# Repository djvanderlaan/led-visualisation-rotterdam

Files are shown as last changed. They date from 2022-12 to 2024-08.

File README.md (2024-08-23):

# LED Visualisation of Rotterdam

The visualisation consists of a number of 3D-printed 'light boxes' for each of the districts in the municipality of Rotterdam in The Netherlands. By inserting punch cards into the model, users are able to select different datasets for the visualisation. This was built as a prototype. The goal is invite users to look and play with statistical data.

Using a map of all districts in The Netherlands ([CBS and Kadaster](https://www.cbs.nl/nl-nl/dossier/nederland-regionaal/geografische-data/wijk-en-buurtkaart-2020)), the districts of Rotterdam were selected and each district was scaled and written to SVG-file. These were converted to 3D-models using OpenSCAD. The boxes were printed in white PLA and the covers were printed in transparent PLA. Holes were drilled in the back for the LEDS (took some experimenting to find the correct number and positions). The boxes were attached to each other using a 3D-printing pen and were attached to a muliplex board. 

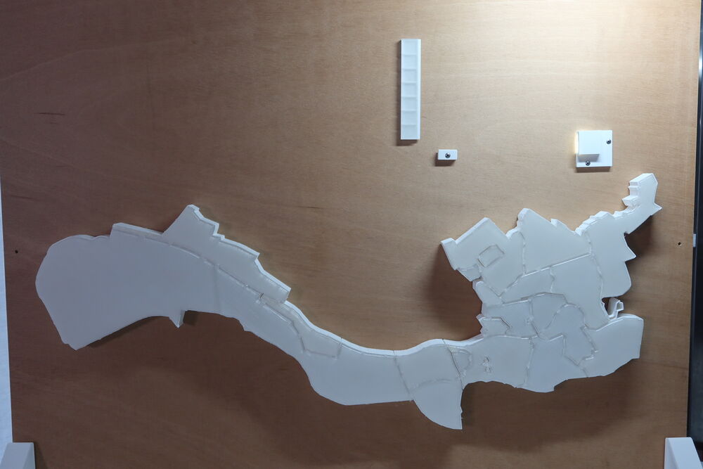
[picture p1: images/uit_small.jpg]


Getting the correct diffusion of the LEDs took some experimenting. In the end small domes were printed in vase mode and glued over the LEDs. Furthermore a layer of LED foam was taped to the inside of the covers. However, even then the lighting in some of the larger districted is still not completely uniform. More LEDs would help; also the diffusors can probably be impoved upon. 

### Card 0: percentage of households with an income below or around the social minimum

[Data is from StatLine](https://opendata.cbs.nl/statline/#/CBS/nl/dataset/84799NED/table?dl=77FE6)

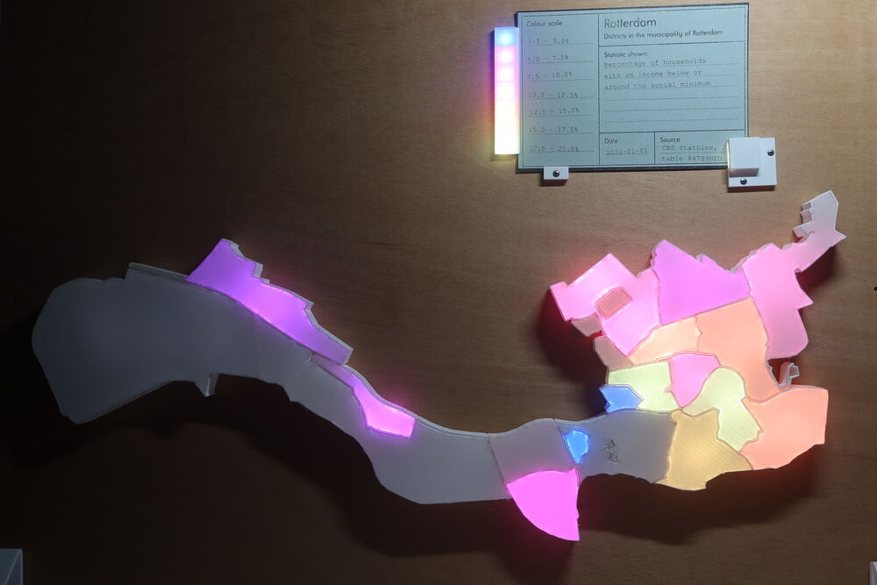
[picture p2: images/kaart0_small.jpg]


### Card 1: number of business locations per square kilometre

[Data is from StatLine](https://opendata.cbs.nl/statline/#/CBS/nl/dataset/84799NED/table?dl=77FE7)

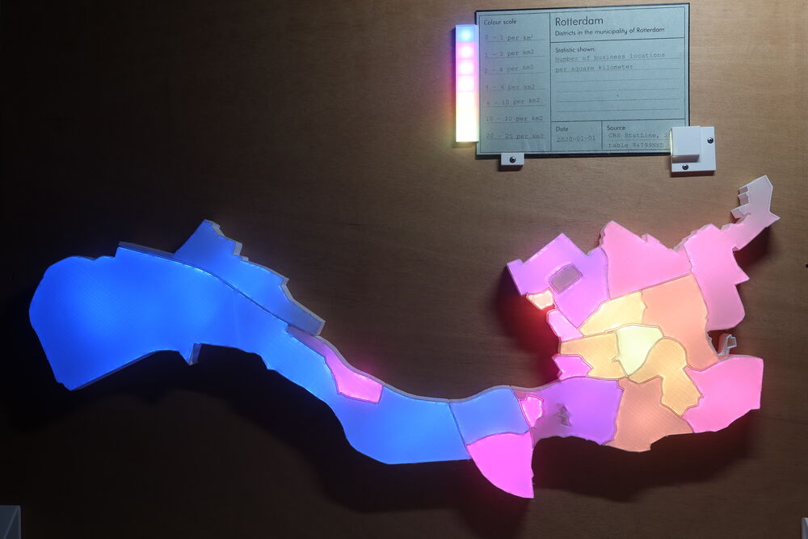
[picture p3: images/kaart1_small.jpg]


### Card 2: Degree of urbanisation as measured by the local address density

[Data is from StatLine](https://opendata.cbs.nl/statline/#/CBS/nl/dataset/84799NED/table?dl=77FE4)

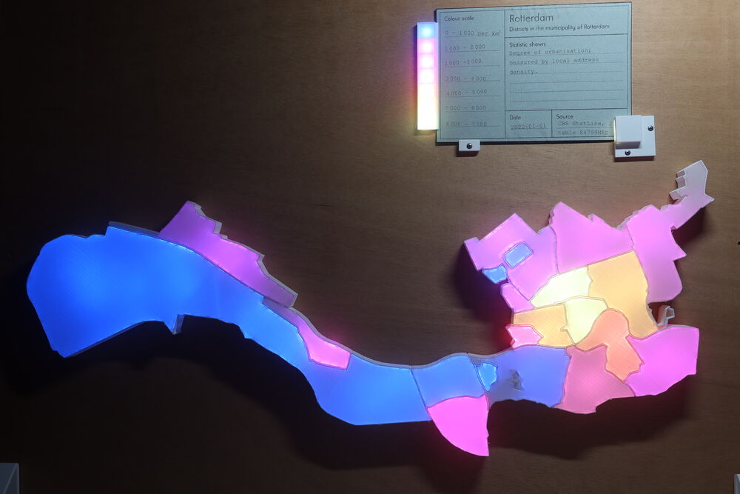
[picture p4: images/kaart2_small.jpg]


### Card 3: Average social economic status based on welfare, education and recent labour force participation

[Data is from StatLine](https://opendata.cbs.nl/statline/#/CBS/nl/dataset/85163NED/table?dl=77FD9)

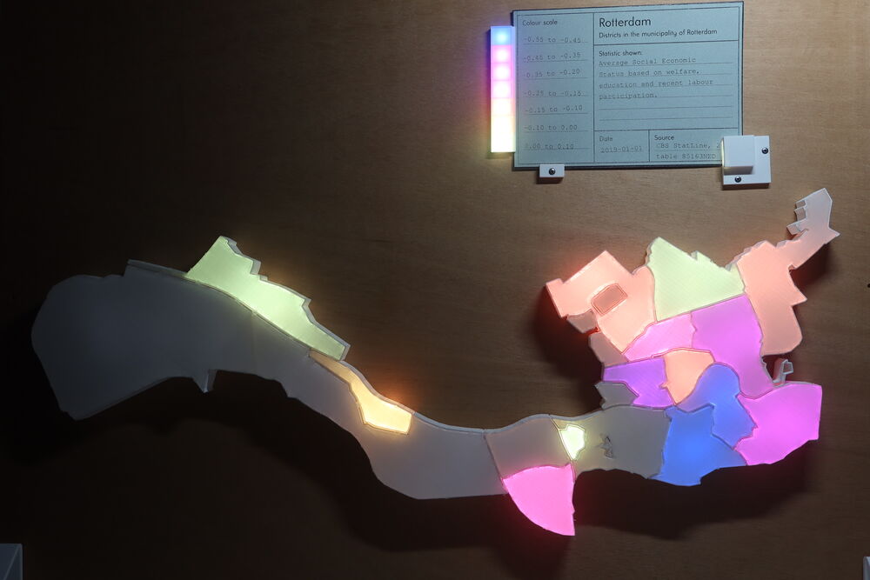
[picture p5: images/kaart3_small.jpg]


### Card 4: Diversity in social economic status

[Data is from StatLine](https://opendata.cbs.nl/statline/#/CBS/nl/dataset/85163NED/table?dl=77FD9)

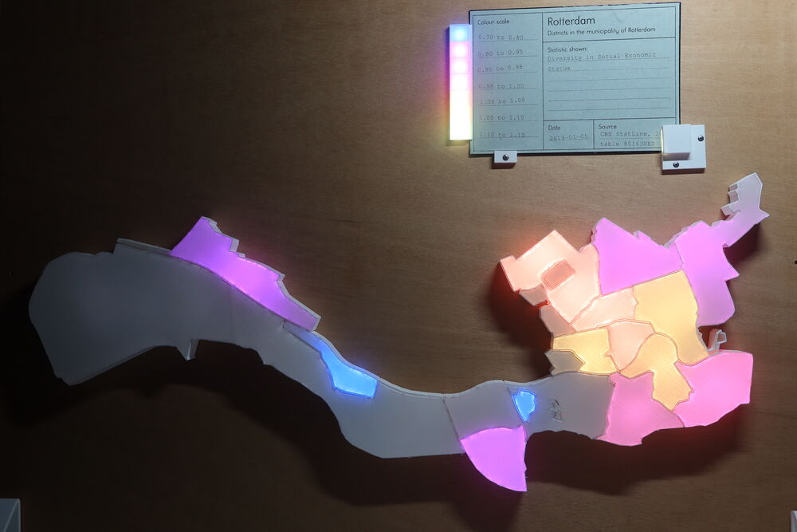
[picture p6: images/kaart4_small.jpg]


### Card 5: Change in the average social economic status from 2014 to 2019

[Data is from StatLine](https://opendata.cbs.nl/statline/#/CBS/nl/dataset/85163NED/table?dl=77FD9)

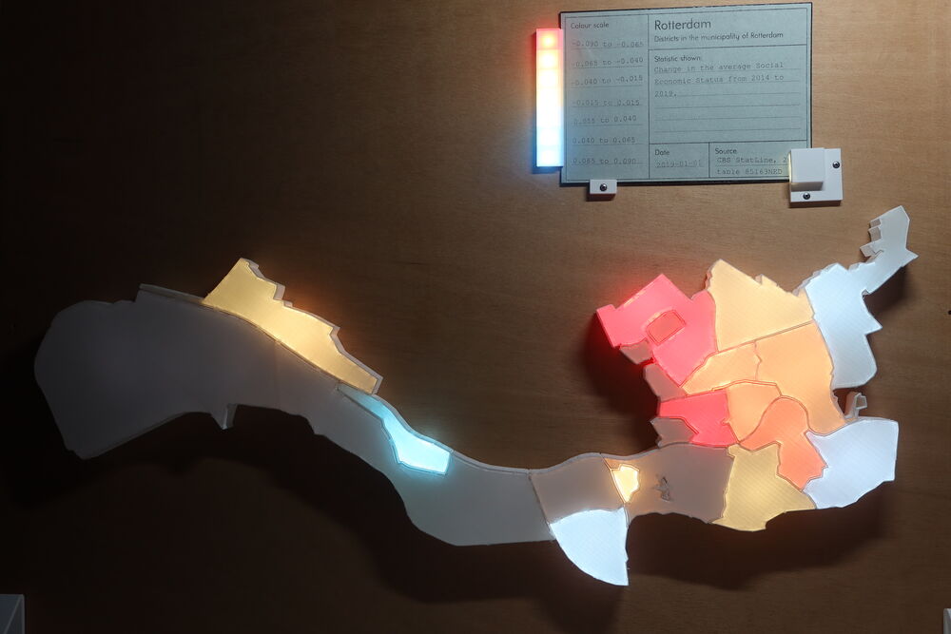
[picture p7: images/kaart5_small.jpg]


### Card 6: Percentage of persons aged younger than 25 years old

[Data is from StatLine](https://opendata.cbs.nl/statline/#/CBS/nl/dataset/84799NED/table?dl=77FE8)

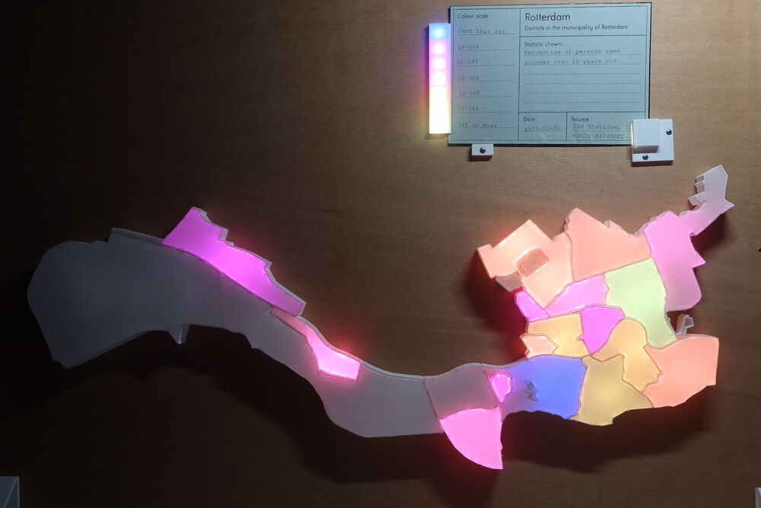
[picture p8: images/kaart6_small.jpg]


### Back side

The visualisation is controlled by an Arduino Uno. All data is in the RAM of Uno. Three LEDs in combination with three photoresistors are responsible for reading out the cards. The cards canhave up to three holes in them. This means that there are 7 possible cards (numbers 0 to 6). All lights active (three holes; or no card) switches of the visualisation. The visualisation itself uses AP102 controllable RGB LEDs. The final 7 LEDS are the colour scale. Colour scales are also stored on the Uno. These consist of 7 colours + a no data colour. Each of the colours comes in two brighnesses. So in total there are 16 colours in one colour scale. The less bright colours are used for the smaller districts. This is to correct for the smaller area of the districts; this makes the light from the LEDs seem brighter. 

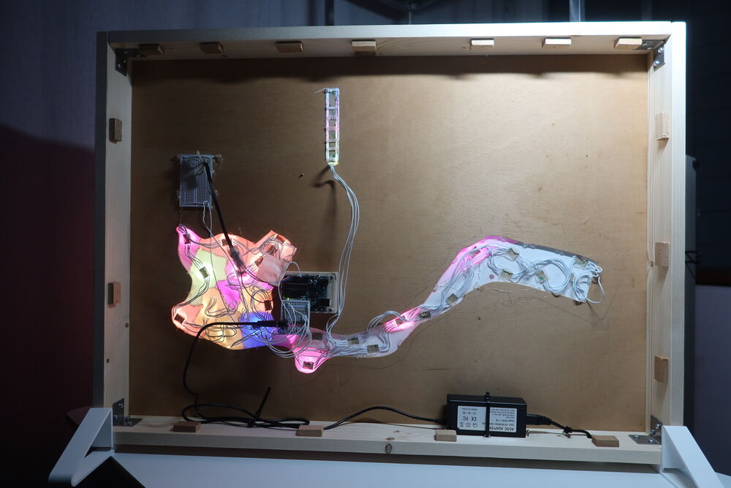
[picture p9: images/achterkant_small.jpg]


## Software

Code was written in the Arduino IDE. Models were made with R, OpenSCAD and FreeCAD. Data for uploading to the Arduino was prepared using R.

## Also see

[ntteloos.nl/rotterdam](https://ntteloos.nl/rotterdam)

[3D-models kan be found on Printables](https://www.printables.com/model/397711-led-visualisation-of-rotterdam).

## Licence

The code and models in this repository are licensed under [CC BY-SA 4.0](https://creativecommons.org/licenses/by-sa/4.0/).

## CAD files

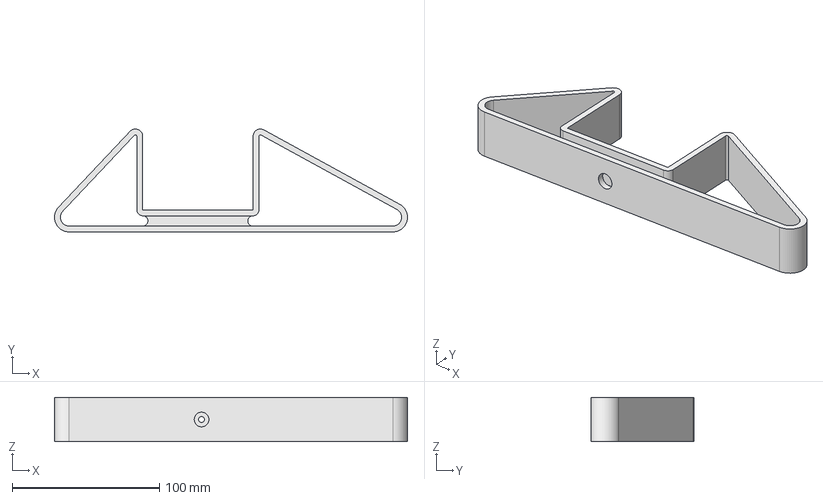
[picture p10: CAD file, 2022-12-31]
models/base/base.FCStd
240.0 x 70.0 x 30.0 mm

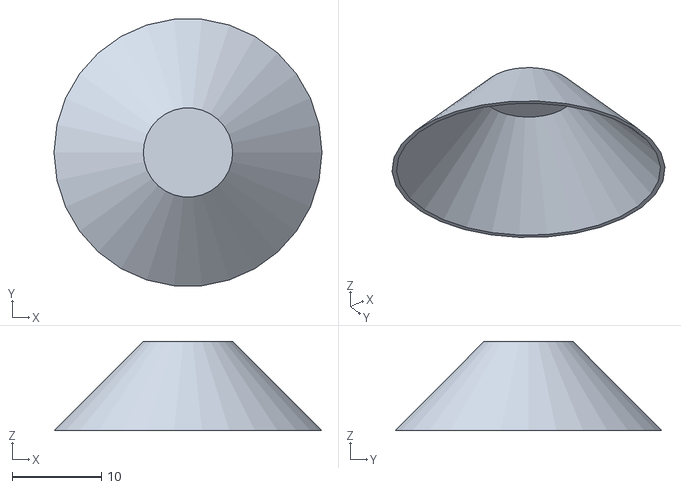
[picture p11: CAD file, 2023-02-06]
models/diffuser/diffuser_v0_30_10.stl
30.0 x 29.8 x 10.0

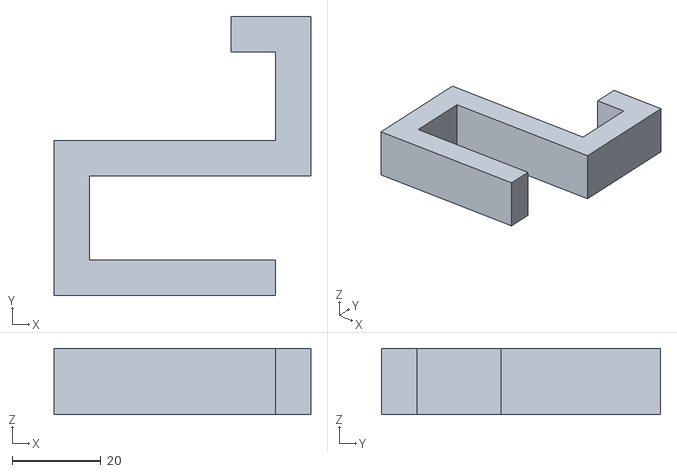
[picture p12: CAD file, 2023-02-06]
models/fixtures/hook.stl
58.0 x 63.0 x 15.0

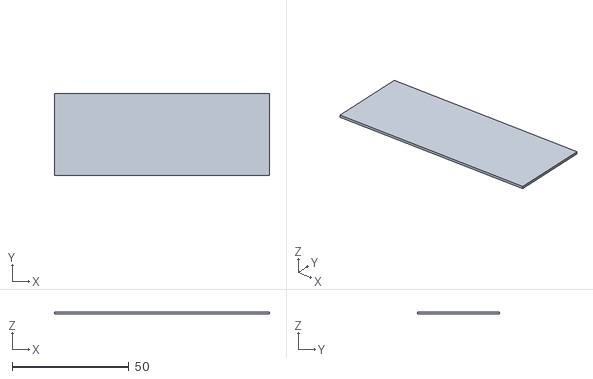
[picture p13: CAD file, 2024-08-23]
punch_card_reader/card_text/signature.stl
92.0 x 35.0 x 1.00

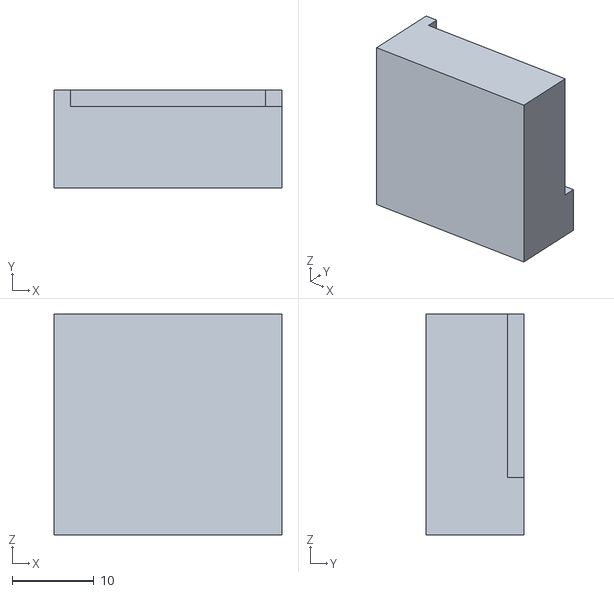
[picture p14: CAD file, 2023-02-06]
punch_card_reader/reader_cover.stl
27.9 x 12.0 x 27.0

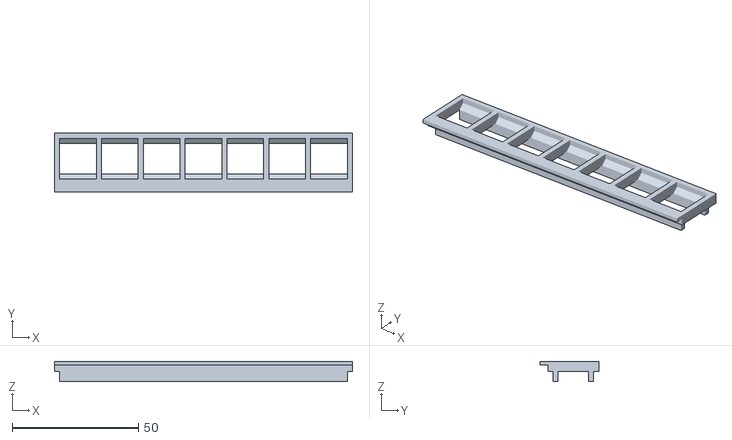
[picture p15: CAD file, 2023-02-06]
models/colourscale/colorscale_box_v1.stl
118.0 x 23.2 x 7.99

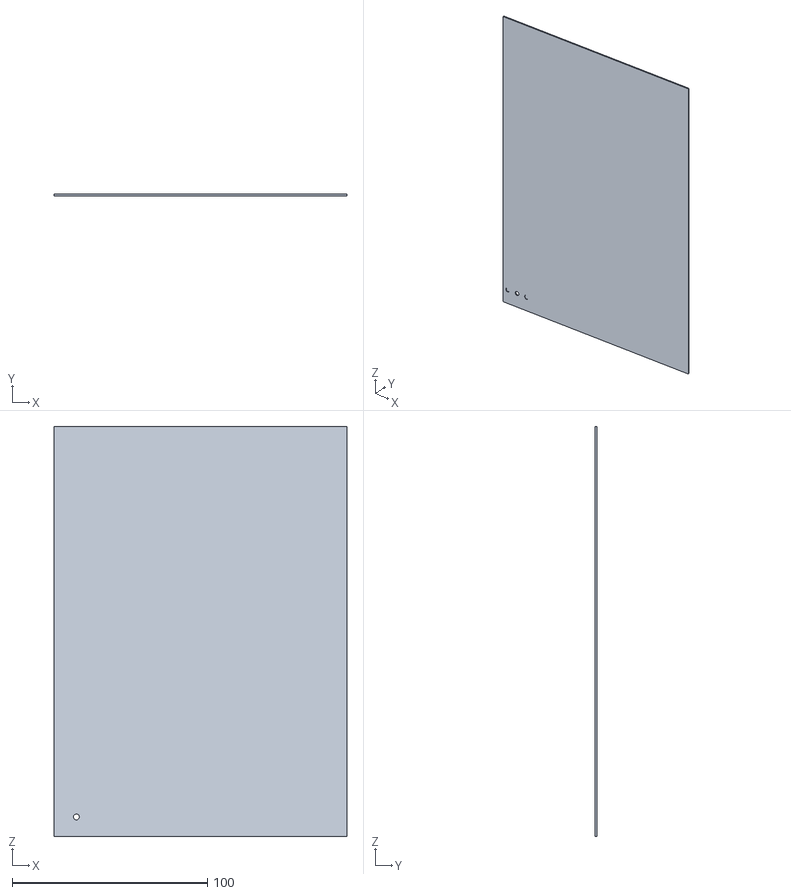
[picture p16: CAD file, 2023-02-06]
punch_card_reader/card_02.stl
150.0 x 0.8 x 210.0

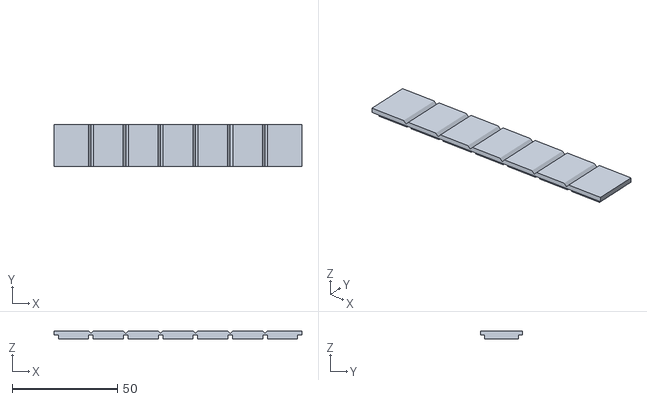
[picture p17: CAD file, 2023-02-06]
models/colourscale/colorscale_cover_v1.stl
118.0 x 20.2 x 4.00

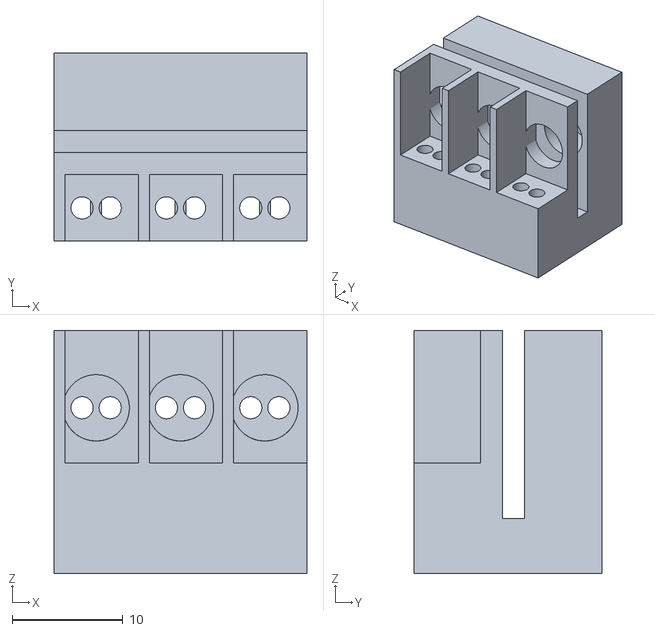
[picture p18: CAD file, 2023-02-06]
punch_card_reader/reader.stl
22.9 x 17.0 x 22.0

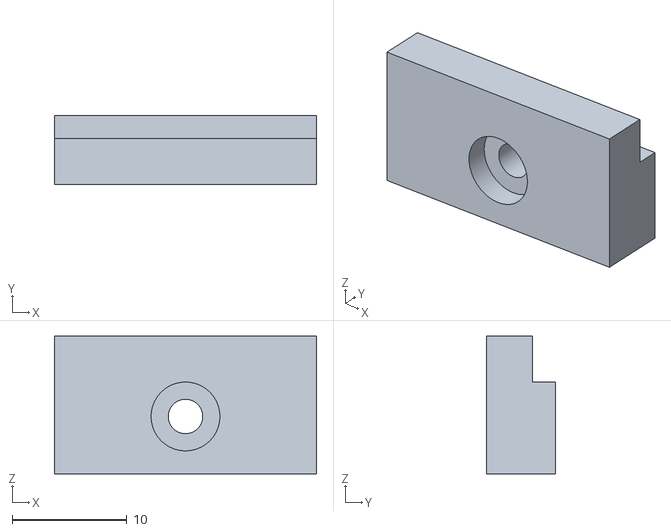
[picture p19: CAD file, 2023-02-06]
punch_card_reader/guide.stl
22.9 x 6.00 x 12.0

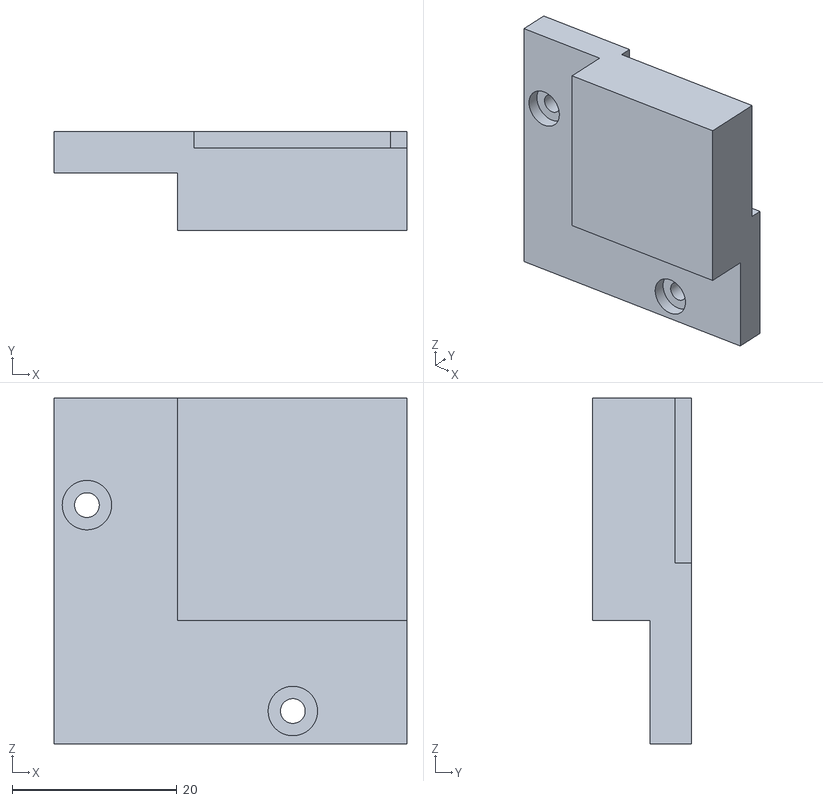
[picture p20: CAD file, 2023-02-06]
punch_card_reader/reader_cover_v3.stl
42.9 x 12.0 x 42.0

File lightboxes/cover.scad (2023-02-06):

filename = "data_output/WK059921A - Rotterdam - Waalhaven-Eemhaven.svg";

wall_thickness = 0.8;
padding = 0.5;
padding_cover = 0.05;

module map(height = 25, offset = 0) {
  linear_extrude(height)
    offset(delta  = -offset)
    import(filename);
}


map(height = 4, offset = padding + wall_thickness + padding_cover);

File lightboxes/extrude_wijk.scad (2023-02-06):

//import("data_output/WK059901A - Rotterdam - Rotterdam Centrum.svg");

filename = "data_output/WK059921A - Rotterdam - Waalhaven-Eemhaven.svg";

wall_thickness = 0.8;
padding = 0.5;

module map(height = 25, offset = 0) {
  linear_extrude(height)
    offset(delta  = -offset)
    import(filename);
}

module grid(height = 100) {
  for (i = [-25:25]) {
    translate([-100, -i*10, 0])
      cube([200, wall_thickness, height]);
    translate([-i*10, -100, 0])
      cube([wall_thickness, 200, height]);
  }  
}

//module grid(height = 25) {
//  for (i = [-10:10]) {
//    for (j = [-10:10]) {
//      translate([j*10, i*10, 0])
//        cylinder(h = height, r = 1);
//    }
//  }  
//}




difference(){
  intersection() {
    grid(height = 25-2);
    map(offset = padding);
  }
  map(height = 25, offset = padding + 3);
}

difference(){
  map(height = 25, offset = padding);
  translate([0, 0, wall_thickness])
  map(height = 25, offset = padding + wall_thickness);
}

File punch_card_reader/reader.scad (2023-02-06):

$fn = 100;

d = 2.54;


module led() {
    r = 5/2;
    h = 6;
    hcyl = h - r;
    color("white")
    translate([0, 0, h - r])
        sphere(r = r);
    color("white")
    cylinder(h = h - r , r = r);
    color("gray")
    translate([-d/2, 0, -30+0.01])
        cylinder(h = 30, r = 0.5);
    color("gray")
    translate([d/2, 0, -30+0.01])
        cylinder(h = 30, r = 0.5);
}


module lsr() {
    cylinder(h = 2, r = 5/2);
    translate([-d/2, 0, -30+0.01])
        cylinder(h = 30, r = 0.5);
    translate([d/2, 0, -30+0.01])
        cylinder(h = 30, r = 0.5);
}


module perfboard(nx, ny) {
    difference() {
        cube([d*(nx+1), d*(ny+1), 2]);
        for (i = [1:nx]) {
            for (j = [1:ny]) {
                translate([d*i, d*j, -0.1])
                    cylinder(h = 2.2, r = 0.5);
            }
        }
    }
}



module reader_part() {
    //Base below the led and bottom plate
    //color("yellow")
    difference() {
        union() {
            cube([d*3, 2+6, 7]);
            cube([d*3, 7 + 3 + 7, 2]);
        }
        union() {
            translate([d*3/2-d/2, 3, -0.1])
                cylinder(r = 1, h = 2+6+0.2);
            translate([d*3/2+d/2, 3, -0.1])
                cylinder(r = 1, h = 2+6+0.2);
        }
    }
    // Opening in front of led
    //color("pink")
    translate([0, 6, 7-0.01])
    difference() {
        cube([d*3, 2, 3+4+5]);
        translate([d*3/2, 2.1, 2+3])
            rotate([90, 0, 0])
            cylinder(r = 6/2, h = 2.2);
    }
    // Side plate next to led
    //color("orange")
    translate([0, 0, 7-0.01])
        cube([1, 2+6, 3+4+5]);
    //color("lightgreen") {
    translate([0, 0, -3])
        cube([1, 7+3+7, 3]);
    translate([d*3-1, 0, -3])
        cube([1, 7+3+7, 3]);
    translate([d*3*0.5-0.5, 0, -3])
        cube([1, 7+3+7, 3]);
    translate([0, 0, -3])
        cube([d*3, 1, 3]);
    //}
    // The part containing the light sensitive resistor
    //color("green")
    difference() {
        translate([0, 7+3, 0])
            cube([d*3, 7, 3+4+5+7]);
        union() {
            translate([3*d/2, -0.1 + 7+3, 12])
                rotate([-90, 0, 0])
                cylinder(r=6/2, h = 5);
            translate([d*3/2-d/2, -0.1 + 7 + 3, 12])
                rotate([-90, 0, 0])
                cylinder(r = 1, h = 2+6+0.2);
            translate([d*3/2+d/2, -0.1 + 7 + 3, 12])
                rotate([-90, 0, 0])
                cylinder(r = 1, h = 2+6+0.2);
        }
    }
}


if (false) {
reader_part();
translate([3*d, 0, 0]) reader_part();
translate([3*d*2, 0, 0]) reader_part();
}

// ==============================================================
// CARD
//color("gray") {
//translate([0, 8.25, 2.0]) 
//
//  difference() {
//  cube([150, 0.8, 210]);
//    
//    translate([d*1.5, -1, 10])
//      rotate([-90, 0, 0])
//      cylinder(r = 1.5, h = 5);
//    translate([d*3+d*1.5, -1.2, 10])
//      rotate([-90, 0, 0])
//      cylinder(r = 1.5, h = 1.5);
//    translate([d*6+d*1.5, -1.2, 10])
//      rotate([-90, 0, 0])
//      cylinder(r = 1.5, h = 1.5);
//  }
//}

//// Example light sensitive resistor
//translate([3*d*0, 0, 0])
//    translate([3*d/2, 7+3+5-1, 12])
//    rotate([90, 0, 0])
//    lsr();
//translate([3*d*1, 0, 0])
//    translate([3*d/2, 7+3+5-1, 12])
//    rotate([90, 0, 0])
//    lsr();
//translate([3*d*2, 0, 0])
//    translate([3*d/2, 7+3+5-1, 12])
//    rotate([90, 0, 0])
//    lsr();
//
//translate([3*d*0, 0, 0])
//    translate([d*3/2, 3, 7.5]) led();
//translate([3*d, 0, 0])
//    translate([d*3/2, 3, 7.5]) led();
//translate([3*d*2, 0, 0])
//    translate([d*3/2, 3, 7.5]) led();
//
//color("darkgreen")
//
//translate([0, 7+3+7+1, 12+3*d])
//    rotate([-90, 0, 0])
//    perfboard(10, 10);



// =============================================================
// COVER
cover_padding = 1;
  cover_thickness = 2;
if (true) {
  
  translate([0, 0, -3]) {
    difference() {
      translate([-cover_thickness, -cover_thickness, -cover_thickness]) {
        cube([9*d+2*cover_thickness+cover_padding, 7+3+cover_thickness, 
          3+4+5+7+3+2*cover_thickness+cover_padding]);
        translate([-15, 7, -15])
        cube([9*d+2*cover_thickness+cover_padding+15, 3+cover_thickness, 
          3+4+5+7+3+2*cover_thickness+cover_padding+15]);
      }
      union() {
        cube([9*d+cover_padding, 7+3, 3+4+5+7+3+cover_padding]);
        translate([0, 7+1, 5])
          cube([100,2, 100]);
      
        translate([-15+2, 0, 12]) {
          rotate([-90, 0, 0])
          cylinder(r = 6/2, h = 7-cover_thickness+2);
          rotate([-90, 0, 0])
          cylinder(r = 3/2, h = 7-cover_thickness+20);
        }
        translate([12, 0, -15+2]) {
          rotate([-90, 0, 0])
          cylinder(r = 6/2, h = 7-cover_thickness+2);
          rotate([-90, 0, 0])
          cylinder(r = 3/2, h = 7-cover_thickness+20);
        }
      }
    }
  }
//  // flange with hole for screw
//  translate([0, 0, -3-(5+1+cover_thickness+4)]) {
//    difference() {
//      translate([-cover_thickness, 7-cover_thickness, -cover_thickness])
//        cube([9*d+2*cover_thickness+cover_padding, 3+cover_thickness, 5+5+cover_thickness]);
//      union() {
//        translate([9*d/2, 0, 2])
//          rotate([-90, 0, 0])
//          cylinder(r = 6/2, h = 7-cover_thickness+2);
//        translate([9*d/2, 0, 2])
//          rotate([-90, 0, 0])
//          cylinder(r = 3/2, h = 7-cover_thickness+20);
//      }
//    }
//  }
//  
//  // flange with hole for screw
//  translate([0, 0, -3-(5+5+cover_thickness)]) {
//    difference() {
//      translate([-cover_thickness, 7-cover_thickness, -cover_thickness])
//        cube([9*d+2*cover_thickness+cover_padding, 3+cover_thickness, 5+5+cover_thickness]);
//      union() {
//        translate([9*d/2, 0, 2])
//          rotate([-90, 0, 0])
//          cylinder(r = 6/2, h = 7-cover_thickness+2);
//        translate([9*d/2, 0, 2])
//          rotate([-90, 0, 0])
//          cylinder(r = 3/2, h = 7-cover_thickness+20);
//      }
//    }
//  }
}


// =============================================================
// GUIDE
if (false) {
  translate([0, 0, -3]) {
    difference() {
      translate([0, 7-cover_thickness, -cover_thickness])
        cube([9*d, 3+cover_thickness, 5+4+cover_thickness]);
      union() {
        translate([-0.1, 7+1, 5])
          cube([100,2, 100]);
        translate([9*d/2, 0, 2])
      rotate([-90, 0, 0])
      cylinder(r = 6/2, h = 7-cover_thickness+2);
    translate([9*d/2, 0, 2])
      rotate([-90, 0, 0])
      cylinder(r = 3/2, h = 7-cover_thickness+20);
      }
    }
   
  }
}

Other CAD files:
models/base/base-Body.stl
punch_card_reader/card_06.stl
punch_card_reader/card_05.stl
punch_card_reader/card_00.stl
punch_card_reader/card_04.stl
punch_card_reader/card_01.stl
punch_card_reader/card_03.stl
models/colourscale/colorscale.scad
lightboxes/data_output/WK059901A - Rotterdam - Rotterdam Centrum.stl
lightboxes/data_output/WK059901A - Rotterdam - Rotterdam Centrum_cover.stl
lightboxes/data_output/WK059901A - Rotterdam - Rotterdam Centrum_cover_extrapad.stl
lightboxes/data_output/WK059901A - Rotterdam - Rotterdam Centrum_cover_nopad.stl
lightboxes/data_output/WK059901A - Rotterdam - Rotterdam Centrum_nopad.stl
lightboxes/data_output/WK059903A - Rotterdam - Delfshaven.stl
lightboxes/data_output/WK059903A - Rotterdam - Delfshaven_cover.stl
lightboxes/data_output/WK059903A - Rotterdam - Delfshaven_cover_extrapad.stl
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

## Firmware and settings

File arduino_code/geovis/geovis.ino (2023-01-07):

#include "flashled.h"
// flashled needs data on pin 11 and clock on 13.
// There are 25 LEDS for the neighbourhoods


// When LOGGING is set to 1 logging info is written to Serial
#define LOGGING 1

// =================================================================
// PALETTE
//
// 0 = Viridis
// 1 = Plasma
// 2 = Sunset
// 3 = SunsetDark
// 4 = ag_GrnYl
// 5 = Zissou 1
const int palette_size = 8*2*4;
//const int palette_num = 1;
const uint8_t palette[] PROGMEM = { 
//Viridis,
0xFF, 0x19, 0x00, 0x16,
0xFF, 0x36, 0x12, 0x0C,
0xFF, 0x4D, 0x34, 0x00,
0xFF, 0x4E, 0x5E, 0x00,
0xFF, 0x37, 0x87, 0x00,
0xFF, 0x14, 0xAA, 0x4E,
0xFF, 0x09, 0xBA, 0xC9,
0xFF, 0x01, 0x02, 0x02,
0xFF, 0x0A, 0x00, 0x09,
0xFF, 0x16, 0x07, 0x05,
0xFF, 0x1F, 0x15, 0x00,
0xFF, 0x1F, 0x25, 0x00,
0xFF, 0x16, 0x36, 0x00,
0xFF, 0x08, 0x44, 0x1F,
0xFF, 0x04, 0x4B, 0x50,
0xFF, 0x00, 0x01, 0x01,
//Plasma,
0xFF, 0x43, 0x04, 0x00,
0xFF, 0x46, 0x00, 0x30,
0xFF, 0x42, 0x03, 0x63,
0xFF, 0x2D, 0x1B, 0x90,
0xFF, 0x0C, 0x47, 0xAC,
0xFF, 0x00, 0x8A, 0xB2,
0xFF, 0x12, 0xE6, 0x9A,
0xFF, 0x01, 0x02, 0x02,
0xFF, 0x1B, 0x01, 0x00,
0xFF, 0x1C, 0x00, 0x13,
0xFF, 0x1A, 0x01, 0x28,
0xFF, 0x12, 0x0B, 0x3A,
0xFF, 0x05, 0x1C, 0x45,
0xFF, 0x00, 0x37, 0x47,
0xFF, 0x07, 0x5C, 0x3D,
0xFF, 0x00, 0x01, 0x01,
//Sunset,
0xFF, 0x58, 0x1B, 0x2E,
0xFF, 0x64, 0x1F, 0x5E,
0xFF, 0x61, 0x29, 0x8C,
0xFF, 0x50, 0x3F, 0xB3,
0xFF, 0x3F, 0x63, 0xC1,
0xFF, 0x3C, 0x8F, 0xC3,
0xFF, 0x54, 0xC0, 0xBB,
0xFF, 0x01, 0x02, 0x02,
0xFF, 0x23, 0x0B, 0x13,
0xFF, 0x28, 0x0C, 0x26,
0xFF, 0x27, 0x11, 0x38,
0xFF, 0x20, 0x19, 0x48,
0xFF, 0x19, 0x28, 0x4D,
0xFF, 0x18, 0x39, 0x4E,
0xFF, 0x21, 0x4D, 0x4B,
0xFF, 0x00, 0x01, 0x01,
//SunsetDark,
0xFF, 0x26, 0x04, 0x39,
0xFF, 0x32, 0x06, 0x65,
0xFF, 0x33, 0x0E, 0x96,
0xFF, 0x2A, 0x23, 0xBF,
0xFF, 0x2B, 0x4D, 0xCA,
0xFF, 0x3A, 0x7A, 0xCC,
0xFF, 0x59, 0xAC, 0xCC,
0xFF, 0x01, 0x02, 0x02,
0xFF, 0x0F, 0x02, 0x17,
0xFF, 0x14, 0x03, 0x28,
0xFF, 0x15, 0x06, 0x3C,
0xFF, 0x11, 0x0E, 0x4C,
0xFF, 0x11, 0x1F, 0x51,
0xFF, 0x17, 0x31, 0x52,
0xFF, 0x24, 0x45, 0x52,
0xFF, 0x00, 0x01, 0x01,
//Fall,
0xFF, 0x0F, 0x22, 0x0F,
0xFF, 0x26, 0x4C, 0x32,
0xFF, 0x4C, 0x86, 0x6D,
0xFF, 0x88, 0xD1, 0xC6,
0xFF, 0x46, 0x8C, 0xA6,
0xFF, 0x18, 0x50, 0x92,
0xFF, 0x06, 0x1E, 0x82,
0xFF, 0x01, 0x02, 0x02,
0xFF, 0x06, 0x0E, 0x06,
0xFF, 0x0F, 0x1E, 0x14,
0xFF, 0x1F, 0x36, 0x2C,
0xFF, 0x36, 0x54, 0x4F,
0xFF, 0x1C, 0x38, 0x42,
0xFF, 0x0A, 0x20, 0x3B,
0xFF, 0x03, 0x0C, 0x34,
0xFF, 0x00, 0x01, 0x01,
//Zissou 1,
0xFF, 0x6F, 0x5C, 0x0E,
0xFF, 0x58, 0x79, 0x1D,
0xFF, 0x4E, 0x8A, 0x57,
0xFF, 0x06, 0x98, 0xAE,
0xFF, 0x02, 0x68, 0xAC,
0xFF, 0x00, 0x3A, 0xAC,
0xFF, 0x03, 0x04, 0xBE,
0xFF, 0x01, 0x02, 0x02,
0xFF, 0x2C, 0x25, 0x06,
0xFF, 0x23, 0x30, 0x0C,
0xFF, 0x1F, 0x37, 0x23,
0xFF, 0x03, 0x3D, 0x46,
0xFF, 0x01, 0x29, 0x45,
0xFF, 0x00, 0x17, 0x45,
0xFF, 0x01, 0x01, 0x4C,
0xFF, 0x00, 0x01, 0x01
};

// =================================================================
// DATASETS
//
const int data_size = 30+7;
const int ndatasets = 6;
const uint8_t data[] PROGMEM = { 
  // dataset 0 = reference dataset with uniform colour and therefore 
  // not an actual dataset
  // 0, 1, 2, 3, 4, 5, 6, 7, 7, 7,
  // 7, 7, 7, 7, 7, 7, 7, 7, 7, 7,
  // 7, 7, 7, 7, 7,     1,1,1,1,1,1,1,1,1,1,1,1,
  // == dataset 0
  // var: HuishOnderOfRondSociaalMinimum_79
  // breaks: 1.5, 5, 7.5, 10, 12.5, 15, 17.5, 20
  5, 6, 3, 6, 15, 4, 3, 15, 15, 3, 2, 3, 4, 4, 7, 8, 8, 7, 2, 7, 1, 7, 1, 7, 7, 7, 7, 7, 7, 7, 6, 5, 4, 3, 2, 1, 0,
  // == dataset 1: bedrijven per km2 2020
  // var: BedrijfsvestigingenTotaal_91
  // breaks: 0, 1, 2, 4, 6, 10, 20, 25
  4, 5, 6, 5, 11, 5, 1, 15, 12, 1, 3, 3, 4, 3, 1, 10, 10, 0, 2, 0, 1, 0, 0, 0, 0, 0, 0, 0, 0, 0, 6, 5, 4, 3, 2, 1, 0,
  // == dataset 2
  // var: Omgevingsadressendichtheid_117
  // breaks: 0, 1000, 2000, 3000, 4000, 5000, 6000, 7000
  3, 4, 6, 5, 9, 6, 1, 8, 8, 1, 2, 2, 5, 2, 0, 11, 8, 0, 2, 0, 1, 0, 1, 0, 0, 0, 0, 0, 0, 0, 6, 5, 4, 3, 2, 1, 0,
  // == dataset 3
  // var: SES
  // breaks: -0.55, -0.45, -0.35, -0.25, -0.15, -0.1, 0, 0.1
  0, 0, 4, 1, 15, 3, 4, 15, 15, 4, 6, 4, 2, 2, 7, 15, 14, 7, 3, 7, 5, 7, 6, 7, 7, 7, 7, 7, 7, 7, 6, 5, 4, 3, 2, 1, 0,
  // == dataset 4
  // var: SES_MAD
  // breaks: 0.7, 0.8, 0.95, 0.98, 1, 1.05, 1.1, 1.15
  3, 5, 4, 5, 15, 4, 4, 15, 15, 4, 2, 2, 5, 3, 7, 15, 8, 7, 1, 7, 0, 7, 1, 7, 7, 7, 7, 7, 7, 7, 6, 5, 4, 3, 2, 1, 0,
  // == dataset 5
  // var: SES_change
  // breaks: -0.09, -0.065, -0.04, -0.015, 0.015, 0.04, 0.065, 0.09
  3, 5, 5, 6, 15, 5, 6, 15, 15, 6, 3, 2, 4, 2, 7, 15, 11, 7, 2, 7, 1, 7, 3, 7, 7, 7, 7, 7, 7, 7, 0, 1, 2, 3, 4, 5, 6,
  // == dataset 6
  // var: jongeren
  // breaks: 0, 22, 24, 26, 28, 30, 32, 34
  5, 5, 2, 5, 10, 3, 4, 15, 15, 4, 4, 3, 6, 4, 0, 12, 10, 7, 3, 7, 3, 7, 2, 7, 7, 7, 7, 7, 7, 7, 6, 5, 4, 3, 2, 1, 0,
  // == dataset 7
  // This is all lights active -> the same as no card; we will use
  // this to switch off the lights
};

// Palettes used by each of the datasets
const int palettes[] = {1, 1, 1, 1, 1, 5, 1};


// =================================================================
// READING THE PUNCHCARD VALUES
// 
const int punchcard1 = A0;
const int punchcard2 = A1;
const int punchcard4 = A2;
const int punchcard_threshold = 300;

int read_punchcard() {
  const int punchcard1_value = analogRead(punchcard1);
  const int punchcard2_value = analogRead(punchcard2);
  const int punchcard4_value = analogRead(punchcard4);
  const int value = (punchcard1_value > punchcard_threshold)*1 +
    (punchcard2_value > punchcard_threshold)*2 +
    (punchcard4_value > punchcard_threshold)*4;
#if LOGGING
  Serial.print("read_punchcard(): Punchcard values: ");
  Serial.print(punchcard1_value);
  Serial.print(",");
  Serial.print(punchcard2_value);
  Serial.print(",");
  Serial.print(punchcard4_value);
  Serial.print("-> value = ");
  Serial.println(value);
#endif
  return value;
}


// =================================================================
// DISPLAYING DATA
// 
void display_data(int dataset) { 
  if (dataset < 0 || dataset > ndatasets) {
#if LOGGING
    Serial.print("display_data(): dataset = ");
    Serial.print(dataset);
    Serial.print(" this is lower than 0 or higher than ndatasets = ");
    Serial.print(ndatasets);
    Serial.println("; turning off LED's");
#endif 
    flashled::turn_off_leds(data_size);
  } else {
#if LOGGING
    Serial.print("display_data(): showing dataset ");
    Serial.println(dataset);
#endif
    const int palette_num = palettes[dataset];
    //const int palette_num = 4;
#if LOGGING
    Serial.print("display_data(): using palette ");
    Serial.println(palette_num);
#endif
    flashled::show_data(data+(dataset)*data_size, palette + palette_num*palette_size, data_size);
  }
}


// =================================================================
// SETUP
//
void setup() {
  flashled::begin();
#if LOGGING
  Serial.begin(9600);
#endif
}


// =================================================================
// LOOP
//
void loop() {
  const int punchcard_value = read_punchcard();
  display_data(punchcard_value);
  delay(500);
}

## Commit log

2022-02-25 Rebuilding arduino code
2022-02-26 Arduino code
2023-01-07 added gamma correction to pallettes
    [geovis.ino]
2023-02-06 punch card reader
    [card_00.stl, card_01.stl, card_02.stl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]
2023-02-13 Link to printables
2024-08-23 wijken rotterdam
    [WK059901A - Rotterdam - Rotterdam Centrum.stl, WK059901A - Rotterdam - Rotterdam Centrum_cover.stl, WK059901A - Rotterdam - Rotterdam Centrum_cover_extrapad.st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]
